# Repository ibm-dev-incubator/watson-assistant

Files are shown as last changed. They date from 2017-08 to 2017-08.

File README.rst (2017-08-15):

Watson Home Assistant Raspberry Pi Hat
======================================

This project is a raspberry pi hat that includes an audio codec with an
integrated microphone, speaker. The intent is to use this to leverage the Watson
APIs to create a voice controlled home assistant. In addition to the speakers
there are 4 addressable RGB LEDs that can be used for more user feedback.

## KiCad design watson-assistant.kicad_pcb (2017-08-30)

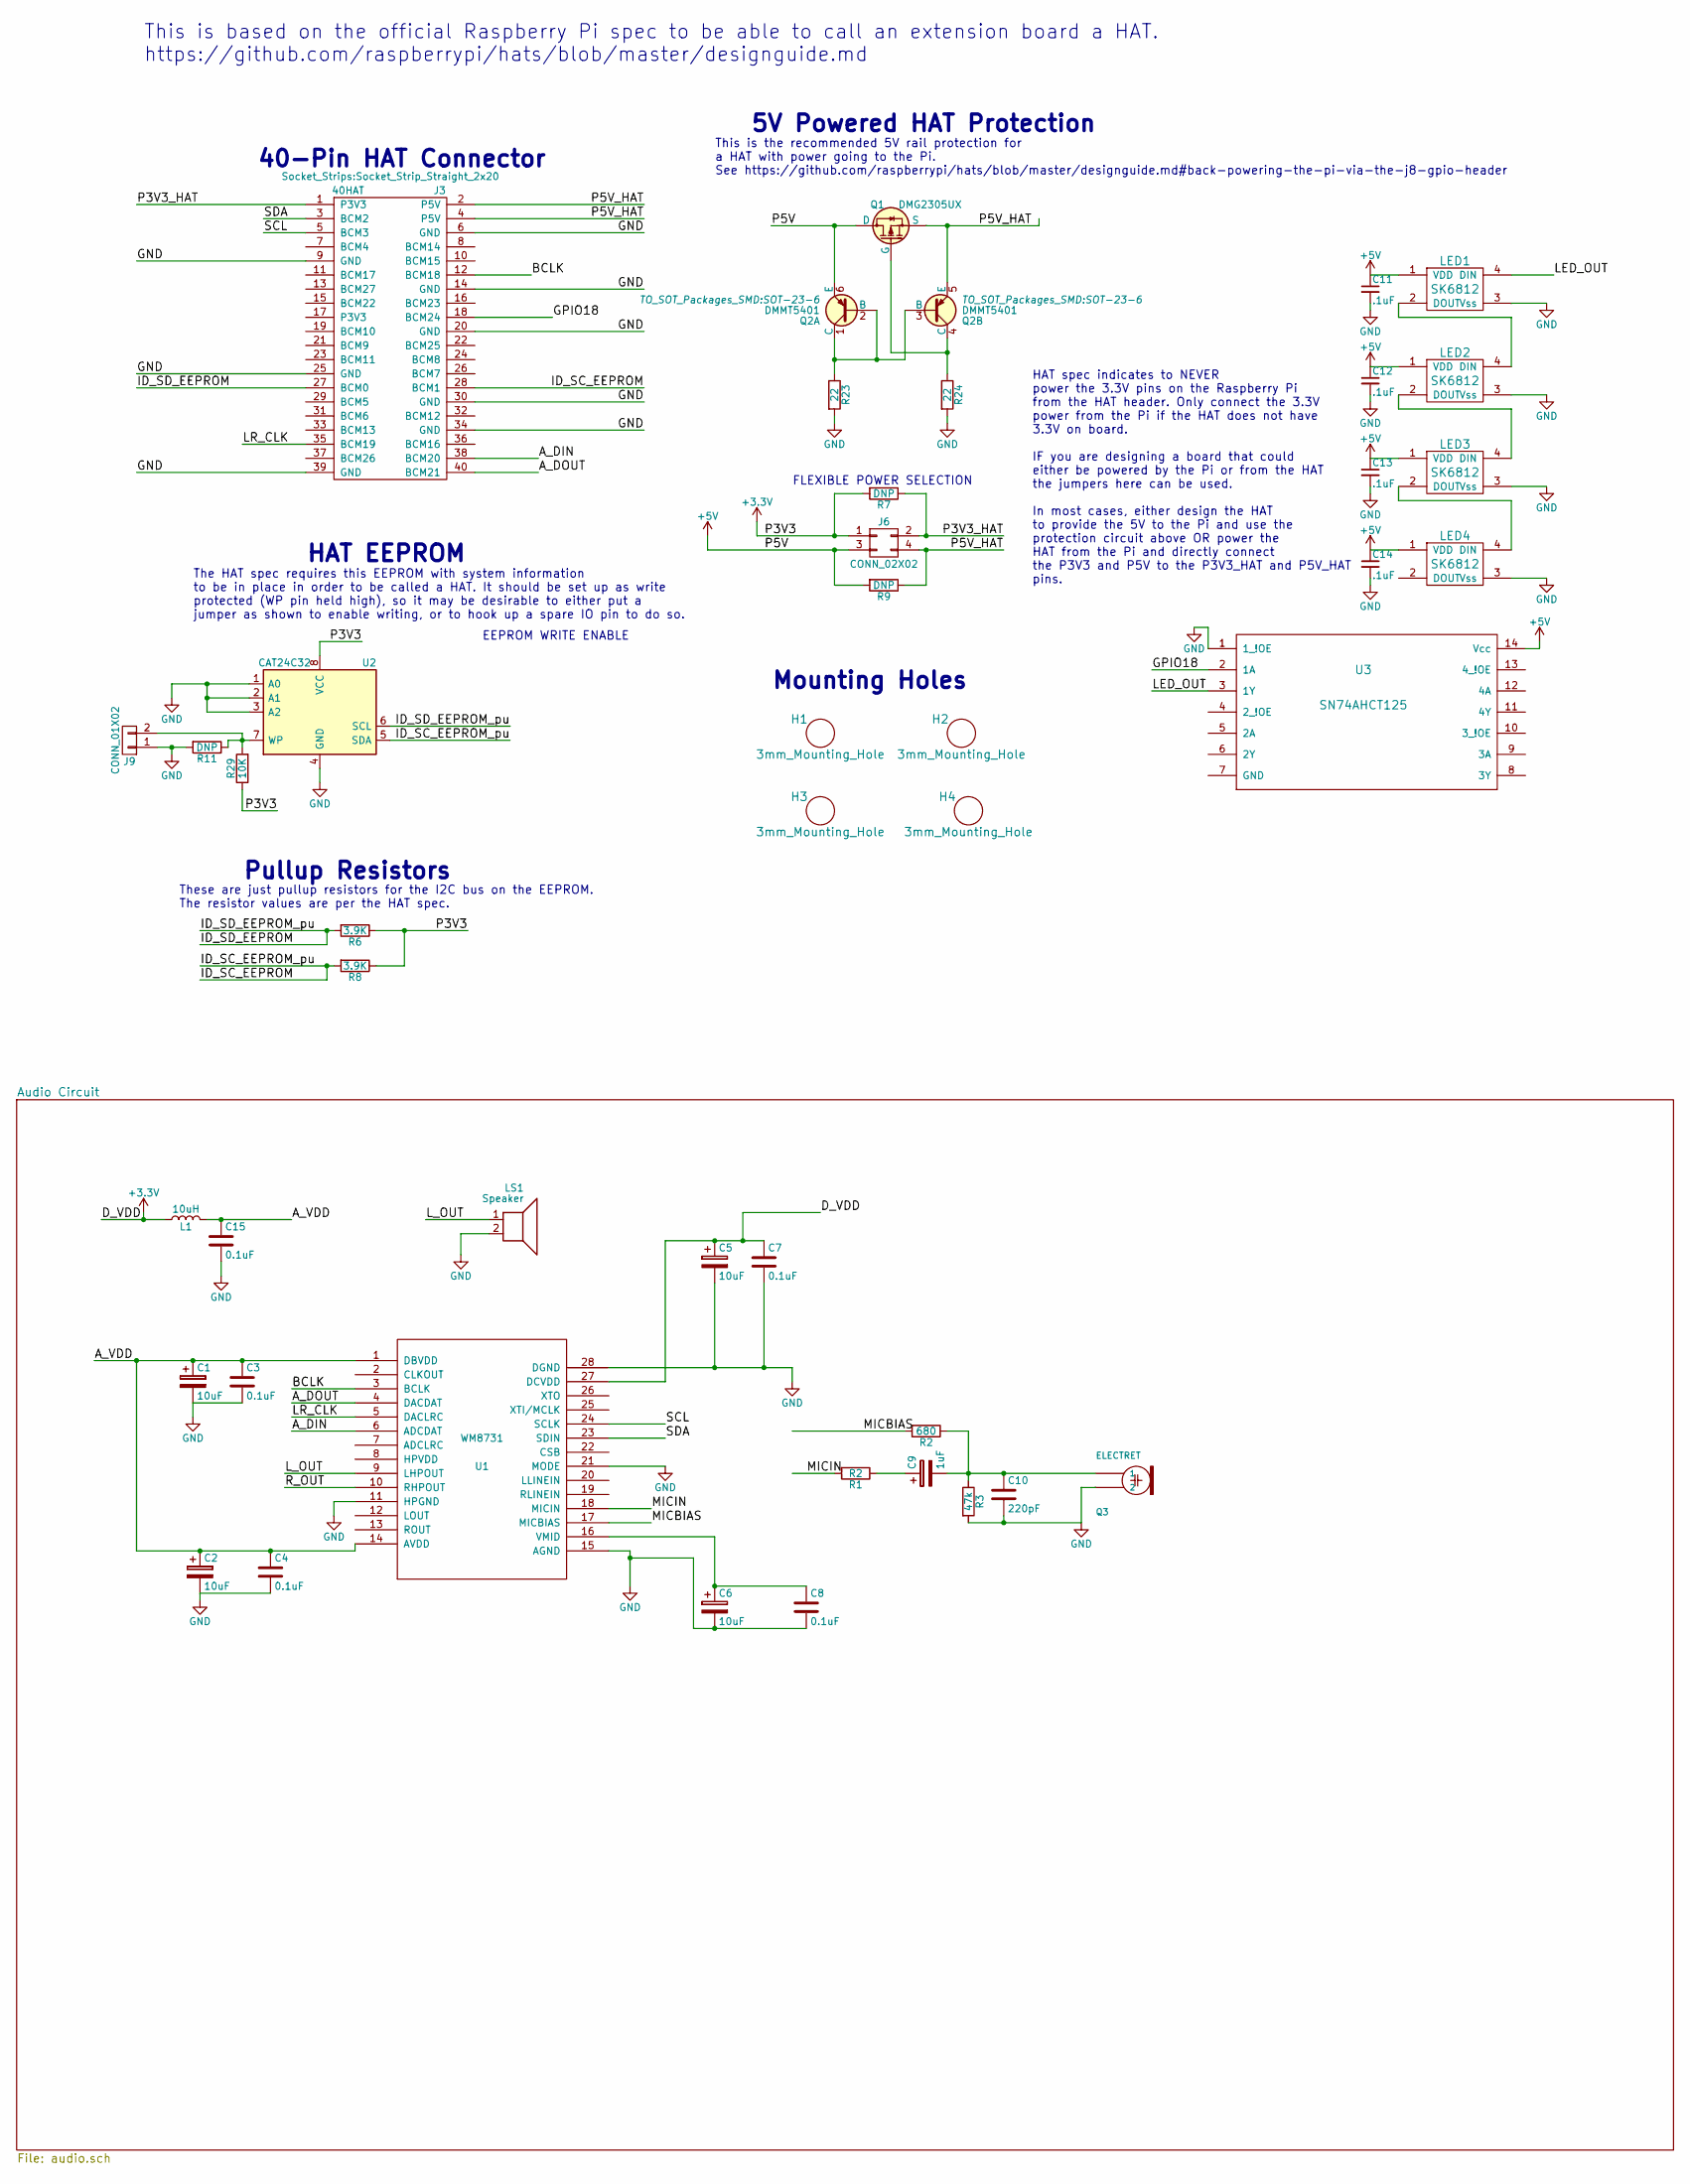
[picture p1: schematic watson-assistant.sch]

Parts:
C1, C2, C5, C6: 10uF; CP_Elec_5x4.5
C3, C4, C7, C8, C15: 0.1uF; C_0805_HandSoldering
C9: 1uF; CP_Elec_5x4.5
C10: 220pF; C_0805_HandSoldering
C11, C12, C13, C14: .1uF; C_0805_HandSoldering
H1, H2, H3, H4: 3mm_Mounting_Hole; NPTH_3mm_ID
J3: 40HAT; Socket_Strip_Straight_2x20
J6: CONN_02X02; Pin_Header_Straight_2x02
J9: CONN_01X02; Pin_Header_Straight_1x02
L1: 10uH; L_0805_HandSoldering
LED1, LED2, LED3, LED4: SK6812; WS2812B
LS1: Speaker; TerminalBlock_Pheonix_PT-3.5mm_2pol
Q1: DMG2305UX; SOT-23
Q2: DMMT5401; SOT-23-6
Q3: ELECTRET; 9.7ELECTRET
R1: R2; R_0603_HandSoldering
R2: 680; R_0603_HandSoldering
R3: 47k; R_0603_HandSoldering
R6, R8: 3.9K; R_0603_HandSoldering; MPN RC0402JR-0722RL
R7, R9, R11: DNP; R_0805_HandSoldering; MPN RC0402JR-0722RL
R23, R24: 22; R_0603_HandSoldering; MPN RC0402JR-0722RL
R29: 10K; R_0603_HandSoldering; MPN RC0402JR-0722RL
U1: WM8731; SSOP-28_5.3x10.2mm_Pitch0.65mm
U2: CAT24C32; SOIC-8_3.9x4.9mm_Pitch1.27mm
U3: SN74AHCT125; DIP-14_W7.62mm_LongPads

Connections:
+3V3: C5.1, C7.1, J6.1, L1.1, R6.1, R7.2, R8.1, R29.1, U1.27 (DCVDD), U2.8 (VCC)
+5V: C11.1, C12.1, C13.1, C14.1, J6.3, LED1.1 (VDD), LED2.1 (VDD), LED3.1 (VDD), LED4.1 (VDD), Q1.3 (D), Q2.6 (E), R9.2, U3.14 (Vcc)
/A_DIN: J3.38 (BCM20), U1.6 (ADCDAT)
/A_DOUT: J3.40 (BCM21), U1.4 (DACDAT)
/A_VDD: C1.1, C2.1, C3.1, C4.1, C15.1, L1.2, U1.1 (DBVDD), U1.14 (AVDD)
/BCLK: J3.12 (BCM18), U1.3 (BCLK)
/GPIO18: J3.18 (BCM24), U3.2 (1A)
/ID_SC_EEPROM: J3.28 (BCM1), R8.2, U2.5 (SDA)
/ID_SD_EEPROM: J3.27 (BCM0), R6.2, U2.6 (SCL)
/LED_OUT: LED1.4 (DIN), U3.3 (1Y)
/LR_CLK: J3.35 (BCM19), U1.5 (DACLRC)
/L_OUT: LS1.1, U1.9 (LHPOUT)
/MICBIAS: R2.2, U1.17 (MICBIAS)
/MICIN: R1.2, U1.18 (MICIN)
/P3V3_HAT: J3.1 (P3V3), J6.2, R7.1
/P5V_HAT: J3.2 (P5V), J3.4 (P5V), J6.4, Q1.2 (S), Q2.5 (E), R9.1
/R_OUT: U1.10 (RHPOUT)
/SCL: J3.5 (BCM3), U1.24 (SCLK)
/SDA: J3.3 (BCM2), U1.23 (SDIN)
GND: C1.2, C2.2, C3.2, C4.2, C5.2, C6.2, C7.2, C8.2, C10.2, C11.2, C12.2, C13.2, C14.2, C15.2, J3.6 (GND), J3.9 (GND), J3.14 (GND), J3.20 (GND), J3.25 (GND), J3.30 (GND), J3.34 (GND), J3.39 (GND), J9.1, LED1.3 (Vss), LED2.3 (Vss), LED3.3 (Vss), LED4.3 (Vss), LS1.2, Q3.+ (2), R3.2, R11.2, R23.2, R24.2, U1.11 (HPGND), U1.15 (AGND), U1.21 (MODE), U1.28 (DGND), U2.1 (A0), U2.2 (A1), U2.3 (A2), U2.4 (GND), U3.1 (1_!OE)
unnamed: C6.1, C8.1, U1.16 (VMID)
unnamed: C9.1, R1.1
unnamed: C9.2, C10.1, Q3.- (1), R2.1, R3.1
unnamed: J9.2, R11.1, R29.2, U2.7 (WP)
unnamed: LED1.2 (DOUT), LED2.4 (DIN)
unnamed: LED2.2 (DOUT), LED3.4 (DIN)
unnamed: LED3.2 (DOUT), LED4.4 (DIN)
unnamed: Q1.1 (G), Q2.4 (C), R24.1
unnamed: Q2.1 (C), Q2.2 (B), Q2.3 (B), R23.1

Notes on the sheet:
FLEXIBLE POWER SELECTION
5V Powered HAT Protection
This is the recommended 5V rail protection for a HAT with power going to the Pi. See https://github.com/raspberrypi/hats/blob/master/designguide.md#back-powering-the-pi-via-the-j8-gpio-header
EEPROM WRITE ENABLE
Pullup Resistors
HAT EEPROM
Mounting Holes
40-Pin HAT Connector
HAT spec indicates to NEVER power the 3.3V pins on the Raspberry Pi from the HAT header. Only connect the 3.3V power from the Pi if the HAT does not have 3.3V on board. IF you are designing a board that could either be powered by the Pi or from the HAT the jumpers here can be used. In most cases, e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
The HAT spec requires this EEPROM with system information to be in place in order to be called a HAT. It should be set up as write protected (WP pin held high), so it may be desirable to either put a jumper as shown to enable writing, or to hook up a spare IO pin to do so.
These are just pullup resistors for the I2C bus on the EEPROM. The resistor values are per the HAT spec.
This is based on the official Raspberry Pi spec to be able to call an extension board a HAT. https://github.com/raspberrypi/hats/blob/master/designguide.md

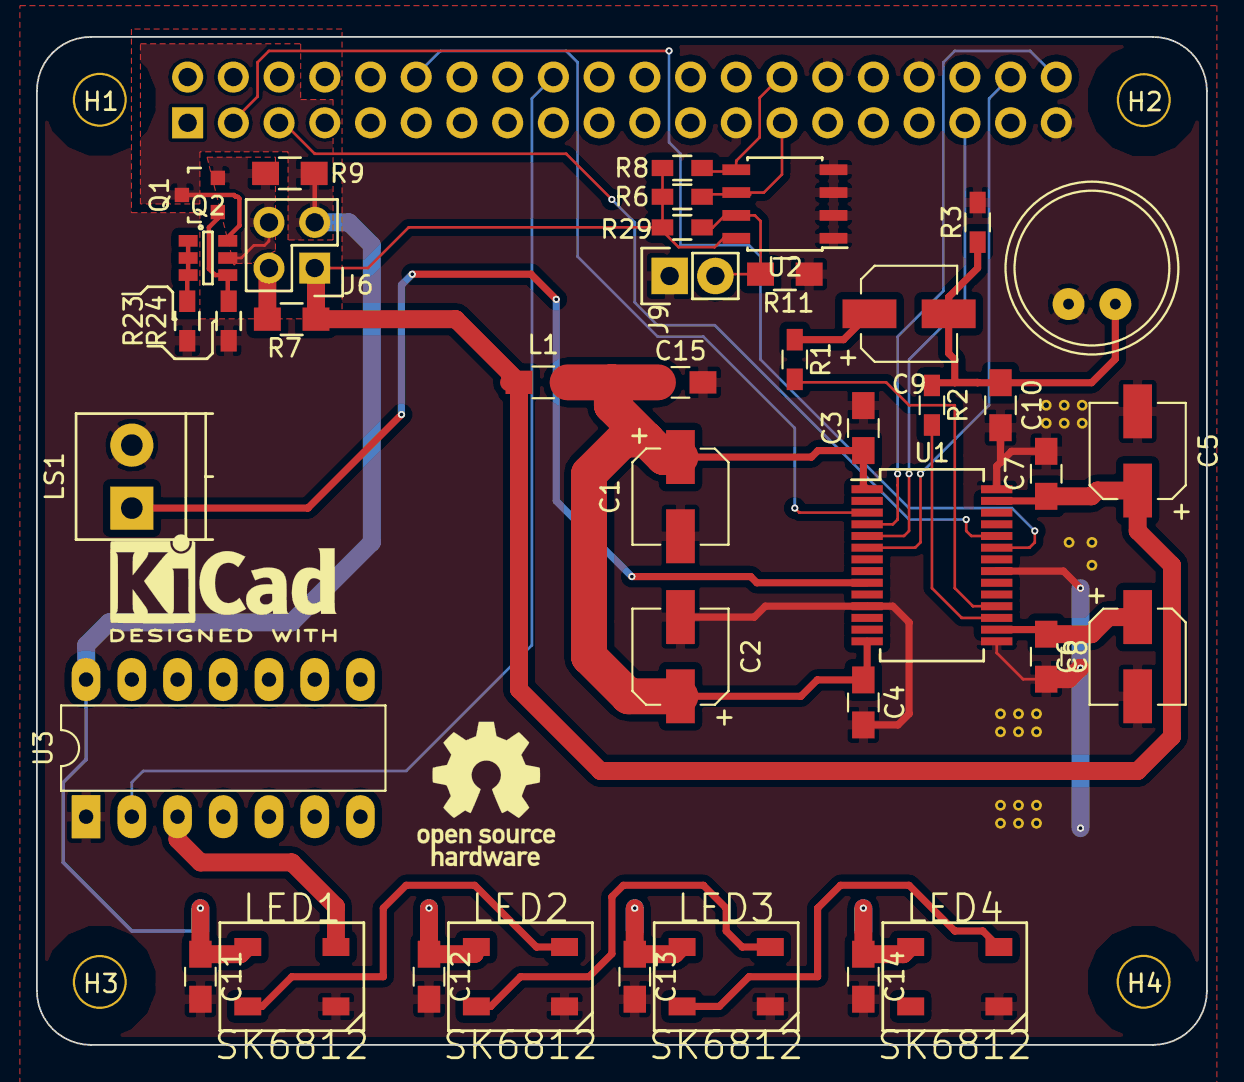
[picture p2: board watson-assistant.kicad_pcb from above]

Board: 4 copper layers, 65.0 x 56.0 mm, 45 parts (1 on the bottom side), 28 nets.

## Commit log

2017-08-15 First version with all pcb nets connected
    [watson-assistant.kicad_pcb, watson-assistant.sch]
2017-08-15 Add silk screen logos
    [watson-assistant.kicad_pcb]
2017-08-30 Add footprints for pcb mounted speakers
2017-08-30 Add terminal for speaker output
    This adds a terminal for a speaker. None of the commonly available pcb
    mount speakers fit on the hat board with all the other components, so
    this adds a terminal on the left edge to wire a speaker to.
    [watson-assistant.kicad_pcb, watson-assistant.sch]
2017-08-30 Remove pcb comment about smt header
    [watson-assistant.kicad_pcb]
